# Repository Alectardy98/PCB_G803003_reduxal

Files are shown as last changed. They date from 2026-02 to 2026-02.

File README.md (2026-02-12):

# GH80-3003 Reduxal

Open-sourced Cherry MX PCB using the Pi Pico (RP2040) for the Cherry G80 3001 line of keyboards. Stock keyboards shipped originally with Cherry MY switches.

G803003_REDUXAL_TOP
G803003_REDUXAL_TOP

Original Placement measurements taken from other open-sourced PCB designs.
https://github.com/evyd13/gh80-series
https://github.com/Gacathon/Chili

## Production
Production files in the JLCPCB Folder

## Firmware
Qmk/Vial Firmware in the firmware folder

Use at your own risk.

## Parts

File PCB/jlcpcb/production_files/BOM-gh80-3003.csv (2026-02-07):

Comment | Designator | Footprint | LCSC | Quantity
1k | R4,R7 | R_0402_1005Metric | C11702 | 2
100nF | C12,C13,C14,C15,C16,C17,C18,C5,C8,C9 | C_0402_1005Metric | C1525 | 10
10uF | C10 | C_0402_1005Metric | C15525 | 1
22pF | C2,C3 | C_0402_1005Metric | C1555 | 2
Conn_01x04_MountingPin | J3 | JST_SH_SM04B-SRSS-TB_1x04-1MP_P1.00mm_Horizontal | C160404 | 1
USB_C | J4 | USB_C_Receptacle_HRO_TYPE-C-31-M-12 | C165948 | 1
1k | R106,R107,R108,R5,R6 | R_0805_2012Metric | C17513 | 5
22 | R100 | R_0805_2012Metric | C17561 | 1
RP2040 | U2 | RP2040-QFN-56 | C2040 | 1
D_Small | D1,D10,D100,D101,D102,D103,D104,D105,D106,D107,D11,D110,D111,D112,D113,D114,D115,D116,D117,D118,D119,D121,D122,D124,D126,D127,D128,D129,D13,D130,D131,D14,D15,D16,D17,D18,D19,D2,D20,D21,D22,D24,D25,D26,D27,D29,D3,D30,D31,D32,D35,D37,D38,D39,D4,D40,D41,D42,D43,D44,D45,D46,D47,D48,D49,D5,D50,D51,D52,D53,D54,D55,D57,D58,D59,D6,D60,D61,D62,D63,D64,D65,D66,D67,D68,D69,D7,D70,D71,D72,D73,D74,D75,D76,D77,D78,D79,D8,D80,D81,D82,D83,D84,D85,D86,D87,D88,D89,D9,D90,D91,D92,D93,D94,D95,D96,D97,D98,D99 | D_SOD-123 | C2099 | 119
27R | R2,R3 | R_0603_1608Metric | C25190 | 2
5.1k | R22,R8 | R_0402_1005Metric | C25905 | 2
0.1uF | C1 | C_0805_2012Metric | C49678 | 1
1uF | C11,C4,C6,C7 | C_0402_1005Metric | C52923 | 4
XC6206 | U5 | SOT-23 | C5446 | 1
500mA | F1,F2 | Fuse_1206_3216Metric | C70076 | 2
SRV05-4 | U3 | SOT-23-6-routable | C85364 | 1
12MHz | Y1 | Crystal_SMD_3225-4Pin_3.2x2.5mm | C9002 | 1
W25Q128JVS | U4 | SOIC-8_5.23x5.23mm_P1.27mm | C97521 | 1

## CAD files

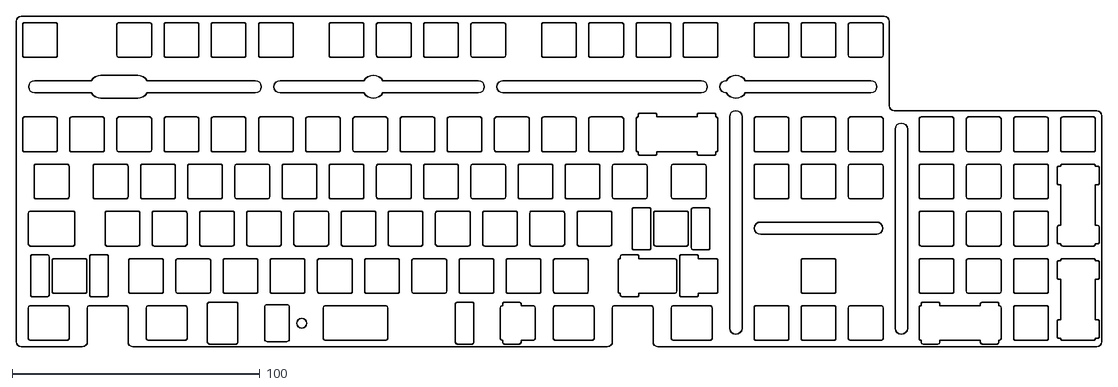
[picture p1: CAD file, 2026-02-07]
plate/gh80-3003-ansi.dxf
438.2 x 133.4

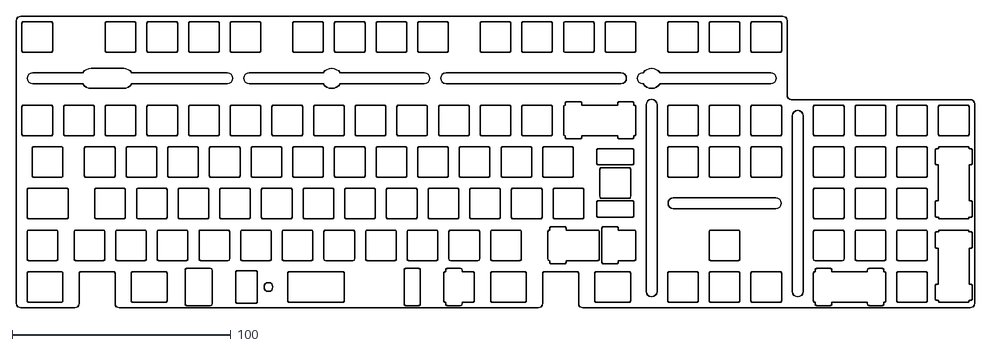
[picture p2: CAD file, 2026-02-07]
plate/gh80-3003-iso.dxf
438.2 x 133.4

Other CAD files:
plate/plate.FCStd

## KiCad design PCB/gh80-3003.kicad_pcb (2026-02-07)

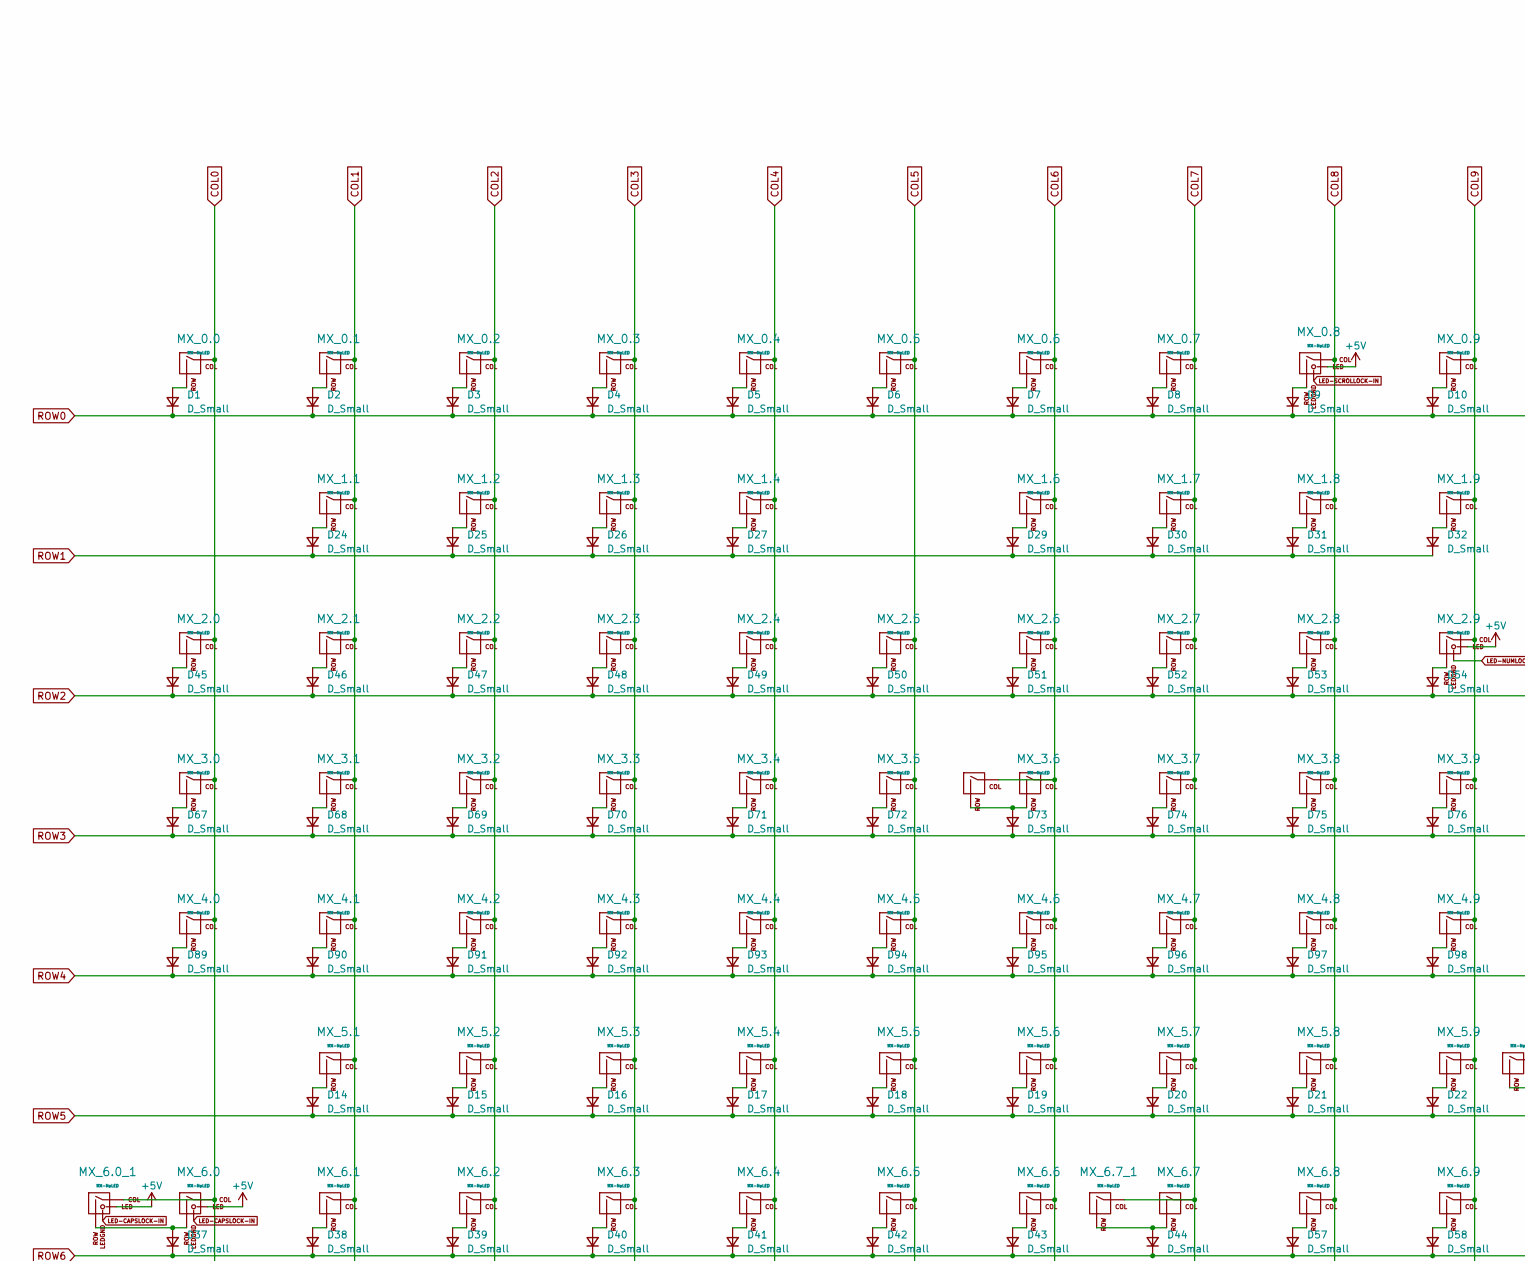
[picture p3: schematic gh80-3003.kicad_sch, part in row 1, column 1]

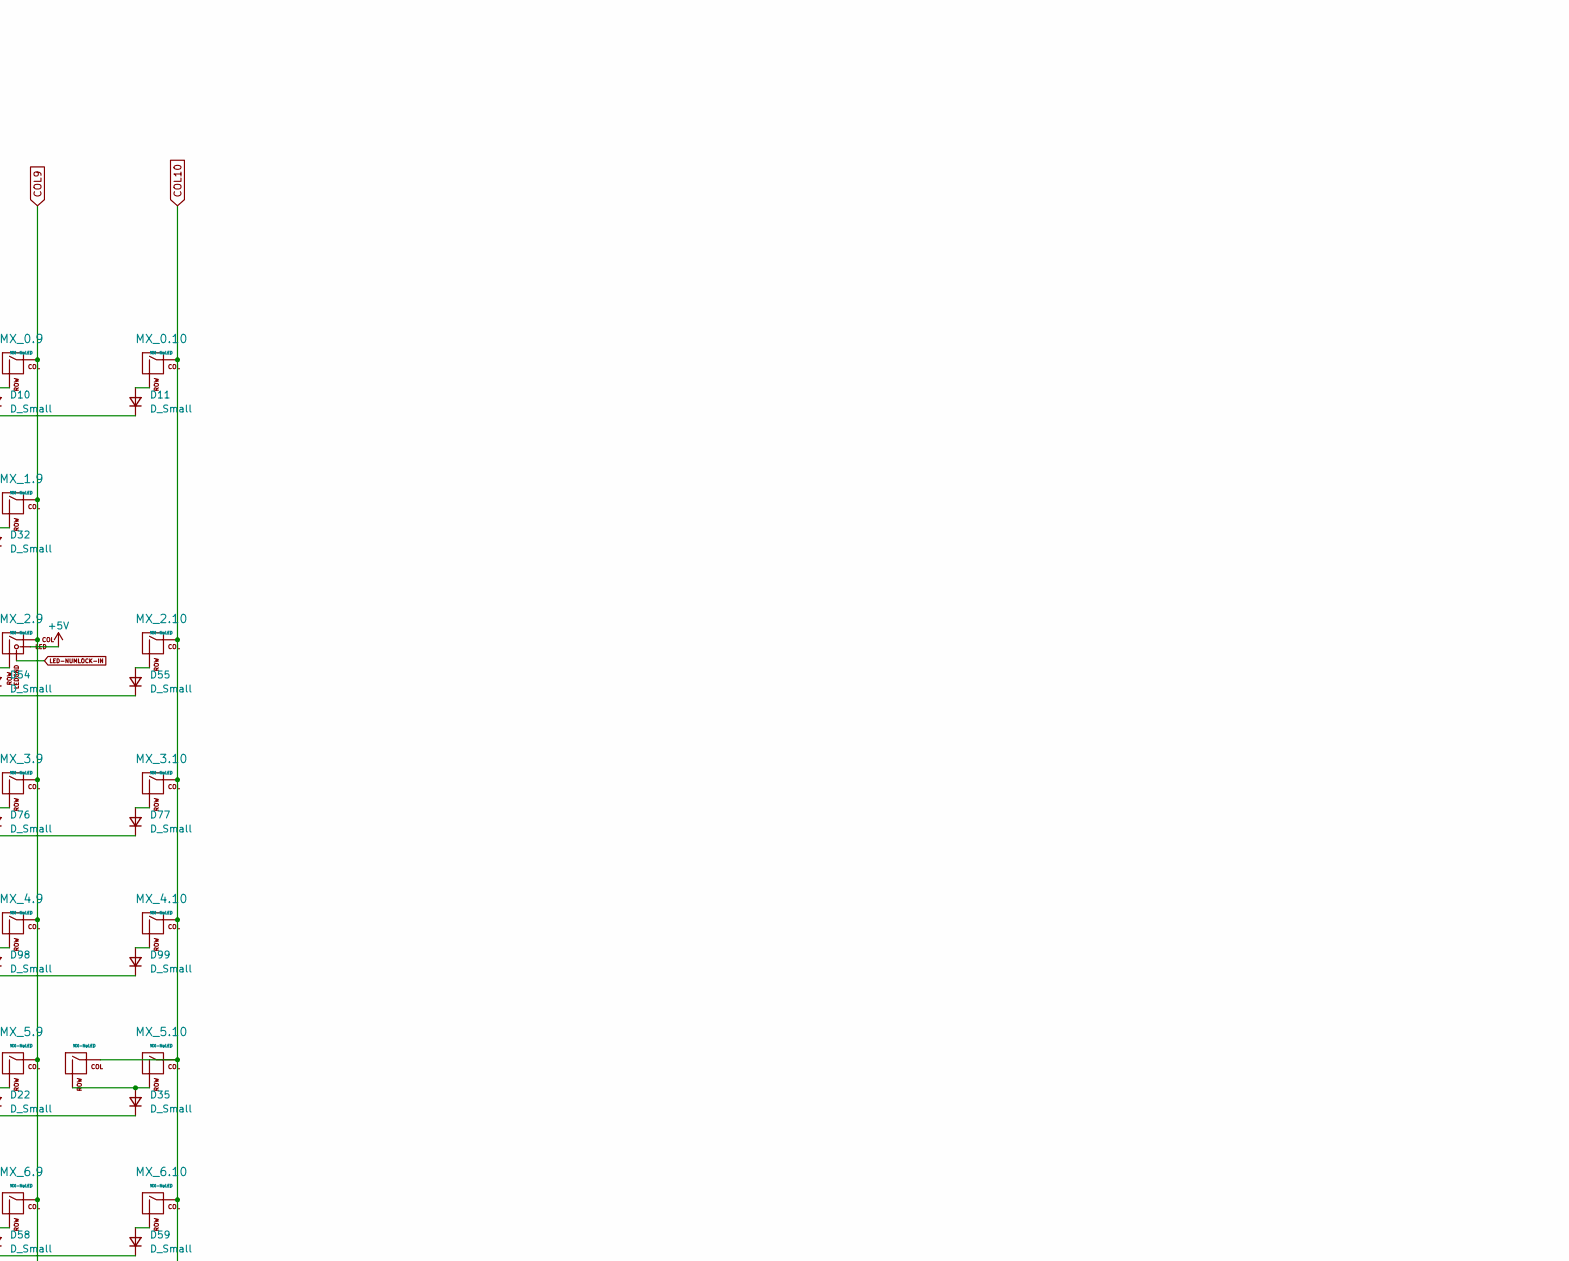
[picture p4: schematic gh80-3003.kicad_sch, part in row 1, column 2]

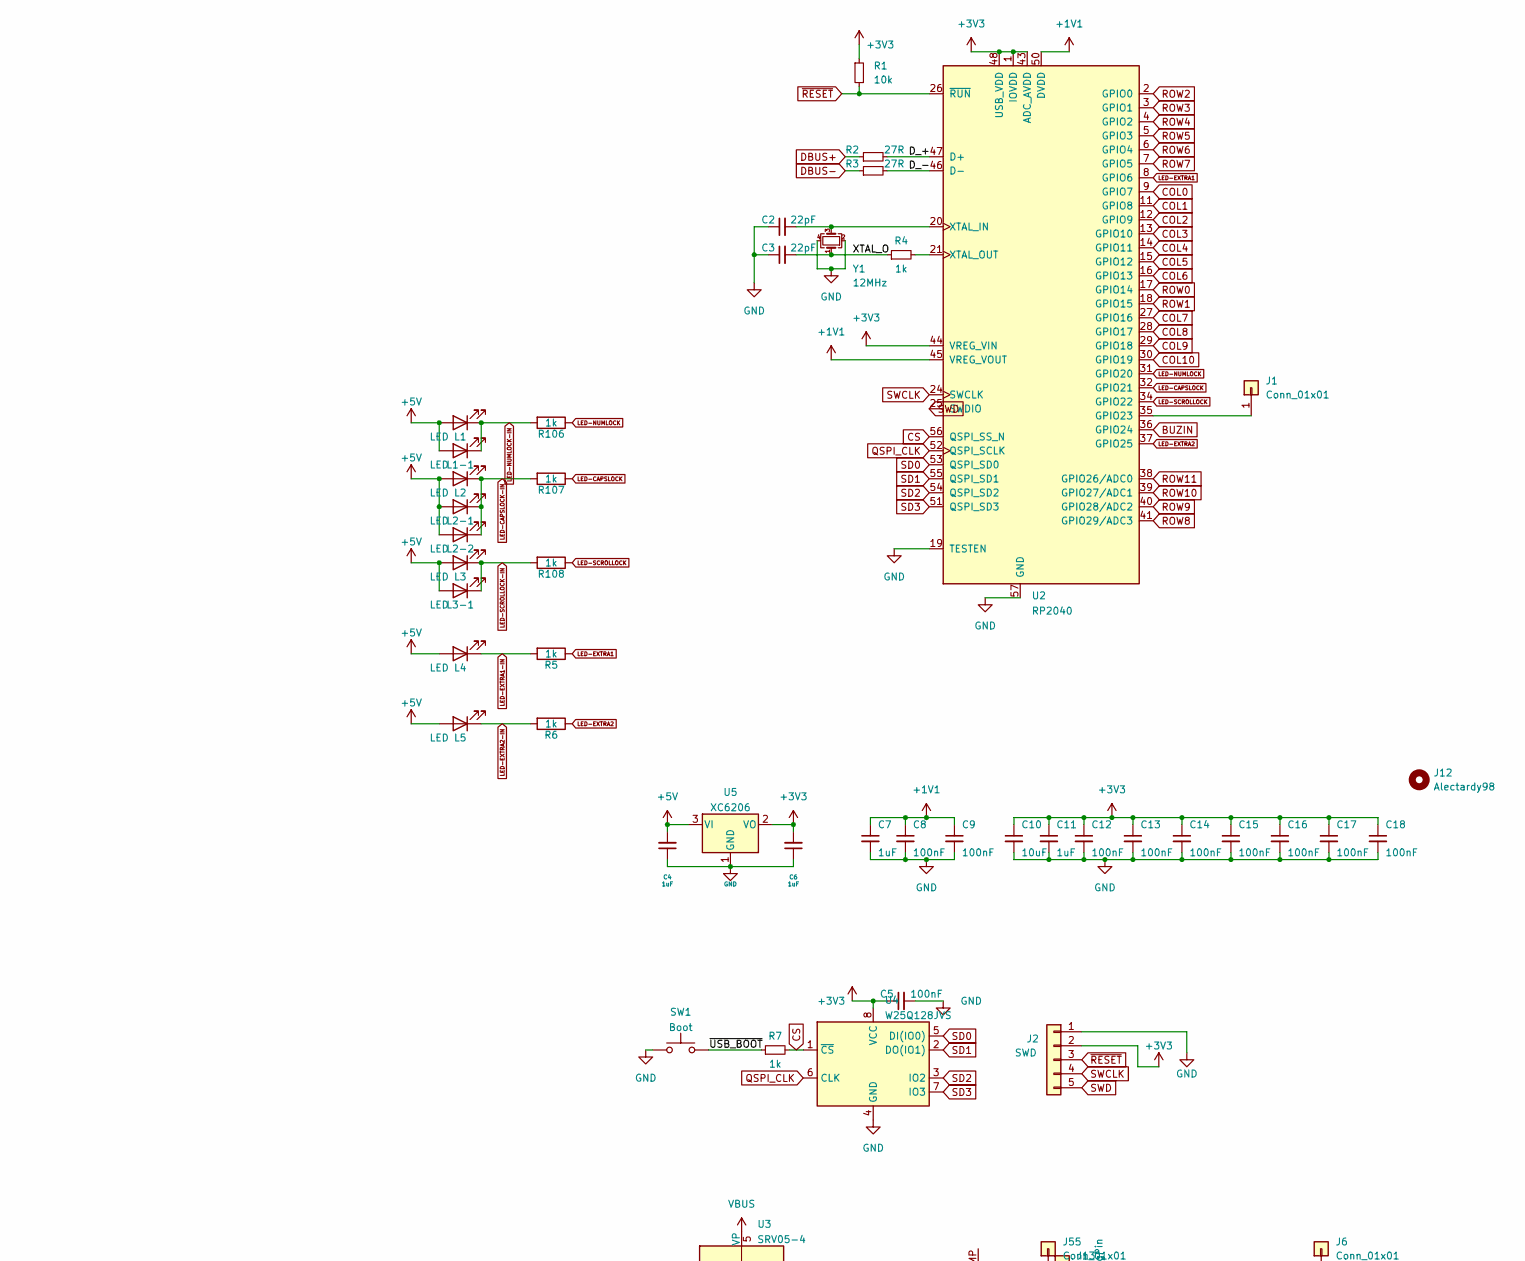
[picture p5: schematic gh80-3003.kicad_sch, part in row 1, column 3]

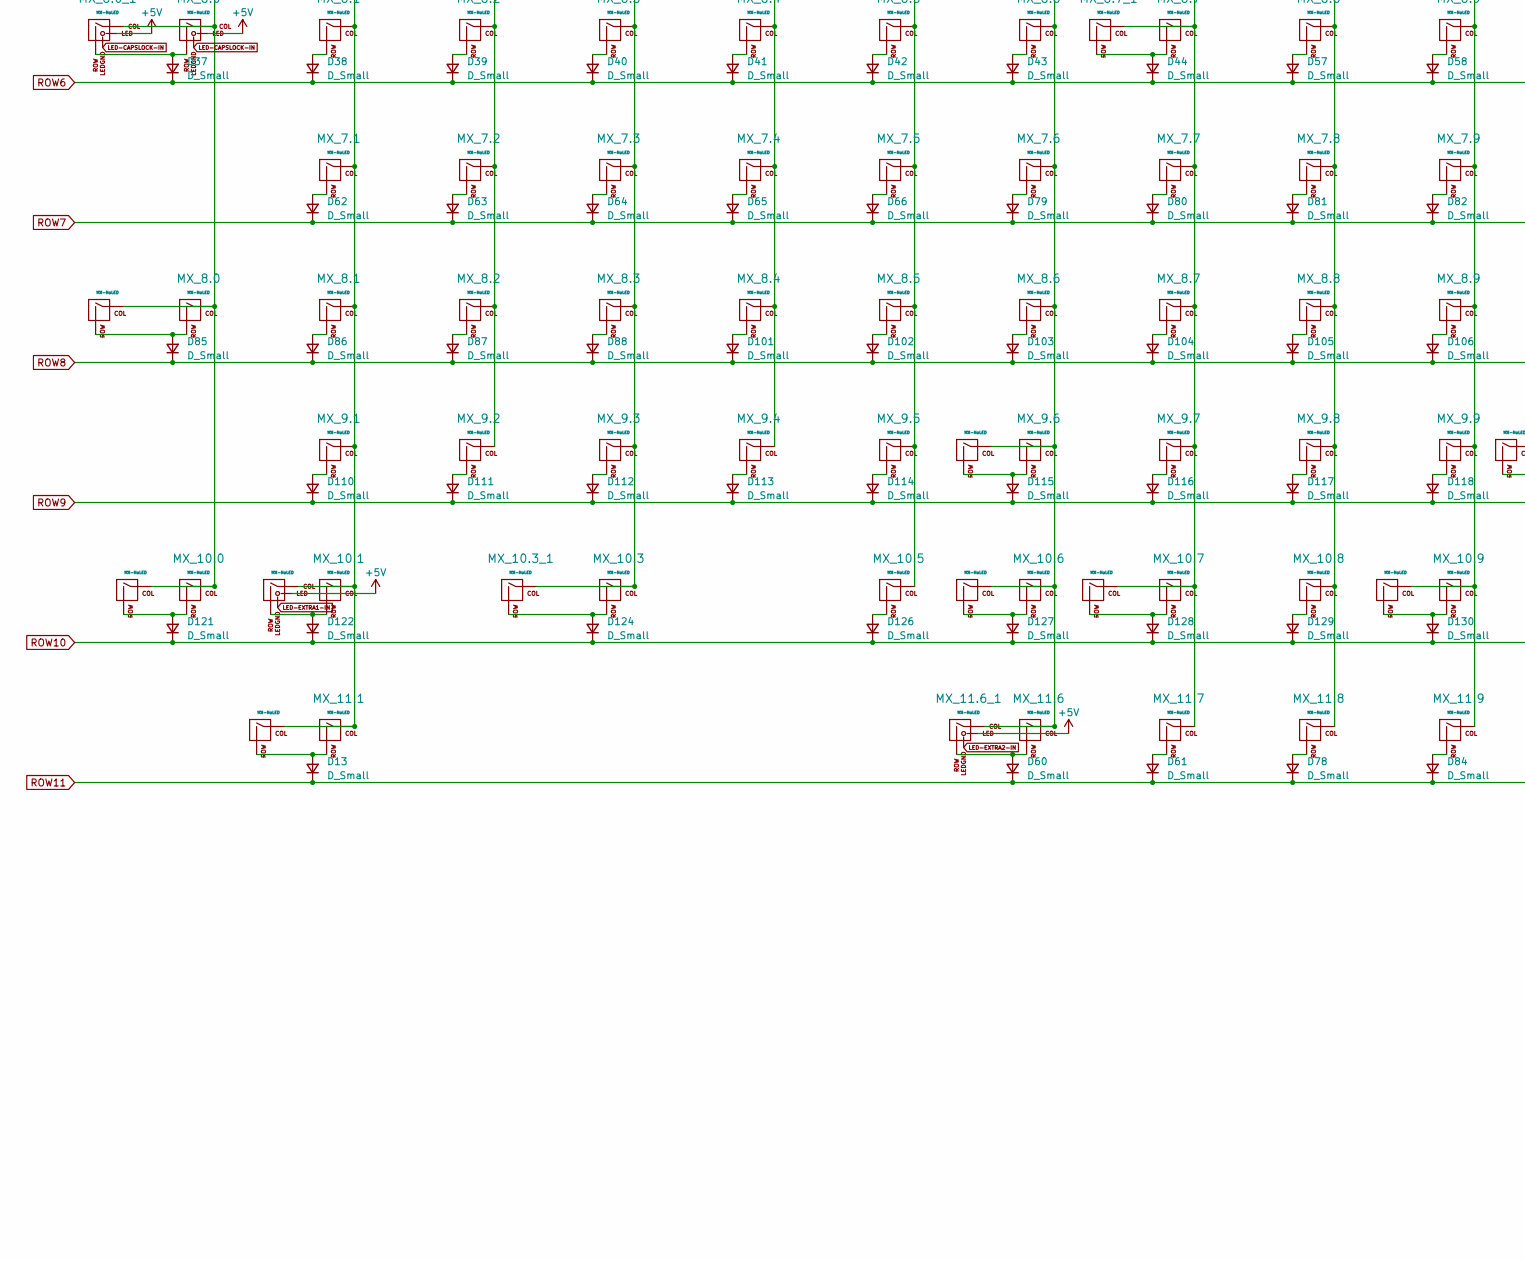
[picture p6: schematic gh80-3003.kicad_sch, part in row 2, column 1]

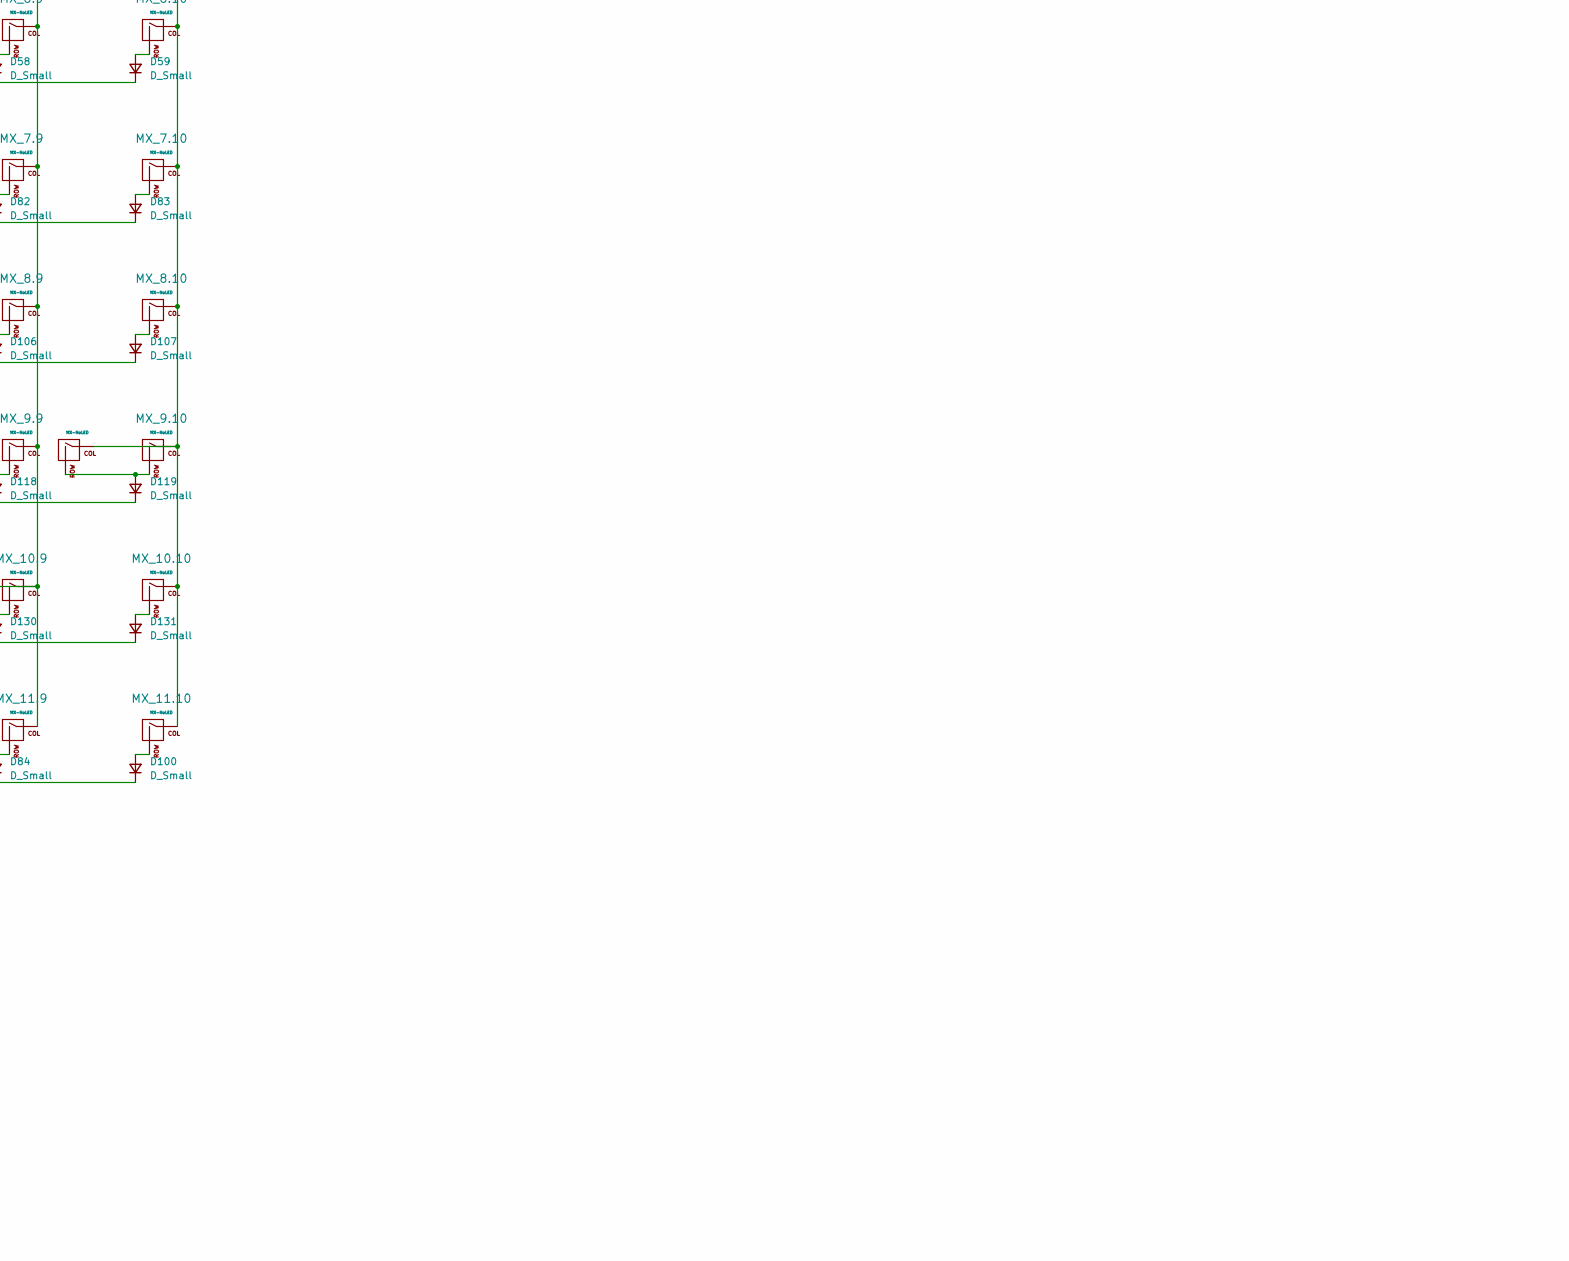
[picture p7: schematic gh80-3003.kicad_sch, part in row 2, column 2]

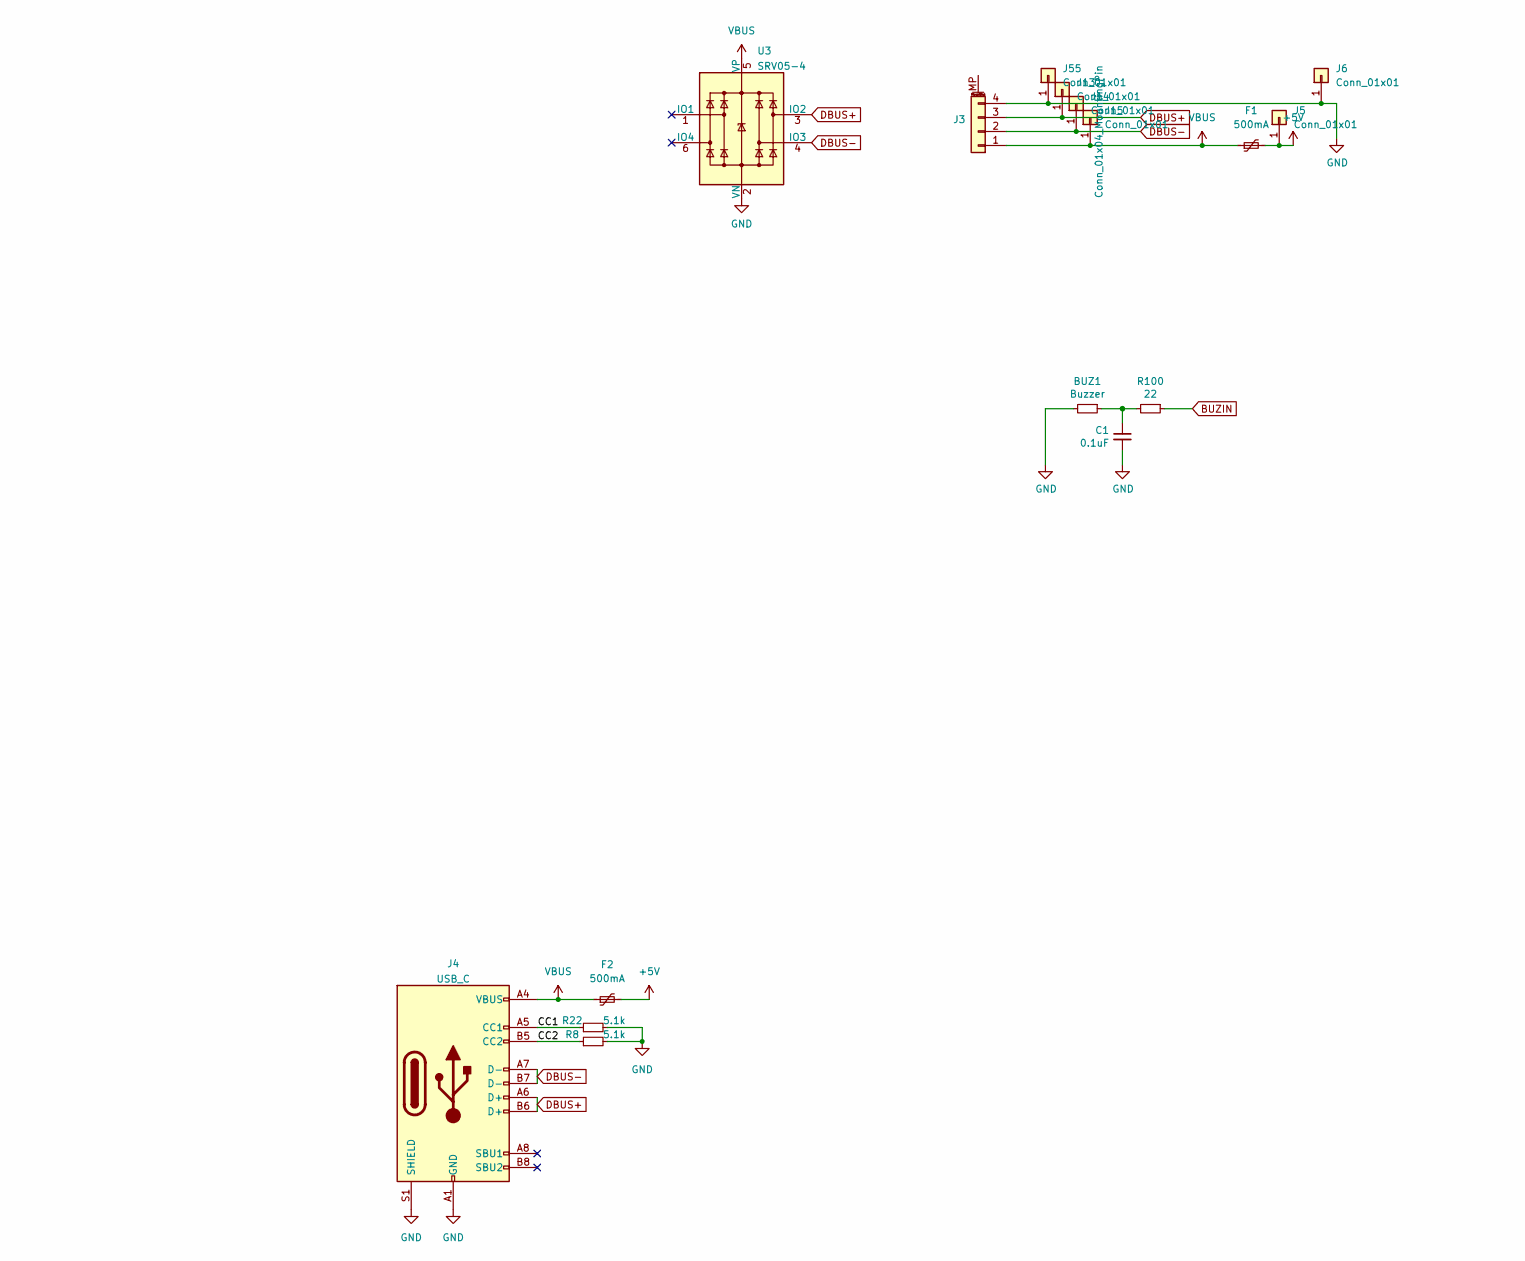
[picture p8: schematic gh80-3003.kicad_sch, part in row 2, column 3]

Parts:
BUZ1: Buzzer; Buzzer_Mallory_AST1109MLTRQ
C1: 0.1uF; C_0805_2012Metric
C2, C3: 22pF; C_0402_1005Metric; LCSC C1555
C4, C6, C7, C11: 1uF; C_0402_1005Metric; LCSC C52923
C5, C8, C9, C12, C13, C14, C15, C16, C17, C18: 100nF; C_0402_1005Metric; LCSC C1525
C10: 10uF; C_0402_1005Metric; LCSC C15525
D1, D2, D3, D4, D5, D6, D7, D8, D9, D10, D11, D13, D14, D15, D16, D17, D18, D19, D20, D21, D22, D24, D25, D26, D27, D29, D30, D31, D32, D35, D37, D38, D39, D40, D41, D42, D43, D44, D45, D46, D47, D48, D49, D50, D51, D52, D53, D54, D55, D57, D58, D59, D60, D61, D62, D63, D64, D65, D66, D67, D68, D69, D70, D71, D72, D73, D74, D75, D76, D77, D78, D79, D80, D81, D82, D83, D84, D85, D86, D87, D88, D89, D90, D91, D92, D93, D94, D95, D96, D97, D98, D99, D100, D101, D102, D103, D104, D105, D106, D107, D110, D111, D112, D113, D114, D115, D116, D117, D118, D119, D121, D122, D124, D126, D127, D128, D129, D130, D131: D_Small; D_SOD-123
F1, F2: 500mA; Fuse_1206_3216Metric; LCSC C70076
J1, J5, J6, J13, J14, J15, J55: Conn_01x01; TestPoint_Plated_Hole_D2.0mm
J2: SWD; PinSocket_1x05_P2.54mm_Vertical
J3: Conn_01x04_MountingPin; JST_SH_SM04B-SRSS-TB_1x04-1MP_P1.00mm_Horizontal
J4: USB_C; USB_C_Receptacle_HRO_TYPE-C-31-M-12; LCSC C165948
J12: Alectardy98; Alectardy98101
L1, L2, L3: LED; LED_D3.0mm
L1-1, L2-1, L2-2, L3-1, L4, L5: LED; CHERRY_MX_LED
MX_0.0, MX_0.1, MX_0.2, MX_0.3, MX_0.4, MX_0.5, MX_0.6, MX_0.7, MX_0.9, MX_0.10, MX_1.1, MX_1.2, MX_1.3, MX_1.4, MX_1.6, MX_1.7, MX_1.8, MX_1.9, MX_2.0, MX_2.1, MX_2.2, MX_2.3, MX_2.4, MX_2.5, MX_2.6, MX_2.7, MX_2.8, MX_2.10, MX_3.0, MX_3.1, MX_3.2, MX_3.3, MX_3.4, MX_3.5, MX_3.6, MX_3.7, MX_3.8, MX_3.9, MX_3.10, MX_4.1, MX_4.2, MX_4.3, MX_4.4, MX_4.5, MX_4.6, MX_4.8, MX_4.9, MX_4.10, MX_5.1, MX_5.2, MX_5.3, MX_5.4, MX_5.5, MX_5.6, MX_5.7, MX_5.8, MX_5.9, MX_5.10, MX_6.1, MX_6.2, MX_6.3, MX_6.4, MX_6.5, MX_6.6, MX_6.8, MX_6.9, MX_6.10, MX_7.1, MX_7.2, MX_7.3, MX_7.4, MX_7.5, MX_7.6, MX_7.7, MX_7.8, MX_7.9, MX_7.10, MX_8.1, MX_8.2, MX_8.3, MX_8.4, MX_8.5, MX_8.6, MX_8.7, MX_8.8, MX_8.9, MX_8.10, MX_9.1, MX_9.2, MX_9.3, MX_9.4, MX_9.5, MX_9.7, MX_9.8, MX_9.9, MX_9.10, MX_10.8, MX_10.9, MX_10.10, MX_11.7, MX_11.8, MX_11.9, MX_11.10: MX-NoLED; MXOnly-1U-NoLED
MX_0.8, MX_2.9, MX_10.1_1, MX_11.6_1: MX-NoLED; MXOnly-1U
MX_3.6_1, MX_10.9_1: MX-NoLED; MXOnly-2U-NoLED
MX_4.0, MX_4.7, MX_10.0_1, MX_10.6_1, MX_10.7_1, MX_11.1_1: MX-NoLED; MXOnly-1.5U-NoLED
MX_5.10_1, MX_9.10_1: MX-NoLED; MXOnly-2U-VerticalStabilizers-NoLED
MX_6.0: MX-NoLED; MXOnly-1.75U
MX_6.0_1: MX-NoLED; MXOnly-1.25U
MX_6.7, MX_8.0_1: MX-NoLED; MXOnly-2.25U-NoLED
MX_6.7_1: MX-NoLED; MXOnly-ISO-ReversedStabilizers-NoLED
MX_8.0, MX_10.0, MX_10.1, MX_10.5, MX_10.6, MX_10.7, MX_11.1, MX_11.6: MX-NoLED; MXOnly-1.25U-NoLED
MX_9.6: MX-NoLED; MXOnly-1.75U-NoLED
MX_9.6_1: MX-NoLED; MXOnly-2.75U-NoLED
MX_10.3: MX-NoLED; MXOnly-6.25U-NoLED
MX_10.3_1: MX-NoLED; MXOnly-7U-NoLED
R1: 10k; R_0402_1005Metric; LCSC C25744
R2, R3: 27R; R_0603_1608Metric; LCSC C25190
R4, R7: 1k; R_0402_1005Metric; LCSC C11702
R5, R6, R106, R107, R108: 1k; R_0805_2012Metric
R8, R22: 5.1k; R_0402_1005Metric; LCSC C25905
R100: 22; R_0805_2012Metric
SW1: Boot; PinSocket_1x02_P2.54mm_Vertical
U2: RP2040; RP2040-QFN-56; LCSC C2040
U3: SRV05-4; SOT-23-6-routable; LCSC C85364
U4: W25Q128JVS; SOIC-8_5.23x5.23mm_P1.27mm; LCSC C97521
U5: XC6206; SOT-23; LCSC C5446
Y1: 12MHz; Crystal_SMD_3225-4Pin_3.2x2.5mm; LCSC C9002

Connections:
+1V1: C7.1, C8.1, C9.1, U2.23 (DVDD), U2.45 (VREG_VOUT), U2.50 (DVDD)
+3V3: C5.1, C6.2, C10.1, C11.1, C12.1, C13.1, C14.1, C15.1, C16.1, C17.1, C18.1, J2.2, R1.1, U2.1 (IOVDD), U2.10 (IOVDD), U2.22 (IOVDD), U2.33 (IOVDD), U2.42 (IOVDD), U2.43 (ADC_AVDD), U2.44 (VREG_VIN), U2.48 (USB_VDD), U2.49 (IOVDD), U4.8 (VCC), U5.2 (VO)
+5V: C4.2, F1.2, F2.2, J5.1, L1.2 (A), L1-1.2 (A), L2.2 (A), L2-1.2 (A), L2-2.2 (A), L3.2 (A), L3-1.2 (A), L4.2 (A), L5.2 (A), MX_0.8.3 (LED), MX_2.9.3 (LED), MX_6.0.3 (LED), MX_6.0_1.3 (LED), MX_10.1_1.3 (LED), MX_11.6_1.3 (LED), U5.3 (VI)
/CC1: J4.A5 (CC1), R22.1
/CC2: J4.B5 (CC2), R8.1
/D_+: R2.2, U2.47 (D+)
/D_-: R3.2, U2.46 (D-)
/XTAL_O: C3.2, R4.1, Y1.1
/~USB_BOOT: R7.1, SW1.2
BUZIN: R100.1, U2.36 (GPIO24)
COL0: MX_0.0.1 (COL), MX_2.0.1 (COL), MX_3.0.1 (COL), MX_4.0.1 (COL), MX_6.0.1 (COL), MX_6.0_1.1 (COL), MX_8.0.1 (COL), MX_8.0_1.1 (COL), MX_10.0.1 (COL), MX_10.0_1.1 (COL), U2.9 (GPIO7)
COL1: MX_0.1.1 (COL), MX_1.1.1 (COL), MX_2.1.1 (COL), MX_3.1.1 (COL), MX_4.1.1 (COL), MX_5.1.1 (COL), MX_6.1.1 (COL), MX_7.1.1 (COL), MX_8.1.1 (COL), MX_9.1.1 (COL), MX_10.1.1 (COL), MX_10.1_1.1 (COL), MX_11.1.1 (COL), MX_11.1_1.1 (COL), U2.11 (GPIO8)
COL2: MX_0.2.1 (COL), MX_1.2.1 (COL), MX_2.2.1 (COL), MX_3.2.1 (COL), MX_4.2.1 (COL), MX_5.2.1 (COL), MX_6.2.1 (COL), MX_7.2.1 (COL), MX_8.2.1 (COL), MX_9.2.1 (COL), U2.12 (GPIO9)
COL3: MX_0.3.1 (COL), MX_1.3.1 (COL), MX_2.3.1 (COL), MX_3.3.1 (COL), MX_4.3.1 (COL), MX_5.3.1 (COL), MX_6.3.1 (COL), MX_7.3.1 (COL), MX_8.3.1 (COL), MX_9.3.1 (COL), MX_10.3.1 (COL), MX_10.3_1.1 (COL), U2.13 (GPIO10)
COL4: MX_0.4.1 (COL), MX_1.4.1 (COL), MX_2.4.1 (COL), MX_3.4.1 (COL), MX_4.4.1 (COL), MX_5.4.1 (COL), MX_6.4.1 (COL), MX_7.4.1 (COL), MX_8.4.1 (COL), MX_9.4.1 (COL), U2.14 (GPIO11)
COL5: MX_0.5.1 (COL), MX_2.5.1 (COL), MX_3.5.1 (COL), MX_4.5.1 (COL), MX_5.5.1 (COL), MX_6.5.1 (COL), MX_7.5.1 (COL), MX_8.5.1 (COL), MX_9.5.1 (COL), MX_10.5.1 (COL), U2.15 (GPIO12)
COL6: MX_0.6.1 (COL), MX_1.6.1 (COL), MX_2.6.1 (COL), MX_3.6.1 (COL), MX_3.6_1.1 (COL), MX_4.6.1 (COL), MX_5.6.1 (COL), MX_6.6.1 (COL), MX_7.6.1 (COL), MX_8.6.1 (COL), MX_9.6.1 (COL), MX_9.6_1.1 (COL), MX_10.6.1 (COL), MX_10.6_1.1 (COL), MX_11.6.1 (COL), MX_11.6_1.1 (COL), U2.16 (GPIO13)
COL7: MX_0.7.1 (COL), MX_1.7.1 (COL), MX_2.7.1 (COL), MX_3.7.1 (COL), MX_4.7.1 (COL), MX_5.7.1 (COL), MX_6.7.1 (COL), MX_6.7_1.1 (COL), MX_7.7.1 (COL), MX_8.7.1 (COL), MX_9.7.1 (COL), MX_10.7.1 (COL), MX_10.7_1.1 (COL), MX_11.7.1 (COL), U2.27 (GPIO16)
COL8: MX_0.8.1 (COL), MX_1.8.1 (COL), MX_2.8.1 (COL), MX_3.8.1 (COL), MX_4.8.1 (COL), MX_5.8.1 (COL), MX_6.8.1 (COL), MX_7.8.1 (COL), MX_8.8.1 (COL), MX_9.8.1 (COL), MX_10.8.1 (COL), MX_11.8.1 (COL), U2.28 (GPIO17)
COL9: MX_0.9.1 (COL), MX_1.9.1 (COL), MX_2.9.1 (COL), MX_3.9.1 (COL), MX_4.9.1 (COL), MX_5.9.1 (COL), MX_6.9.1 (COL), MX_7.9.1 (COL), MX_8.9.1 (COL), MX_9.9.1 (COL), MX_10.9.1 (COL), MX_10.9_1.1 (COL), MX_11.9.1 (COL), U2.29 (GPIO18)
COL10: MX_0.10.1 (COL), MX_2.10.1 (COL), MX_3.10.1 (COL), MX_4.10.1 (COL), MX_5.10.1 (COL), MX_5.10_1.1 (COL), MX_6.10.1 (COL), MX_7.10.1 (COL), MX_8.10.1 (COL), MX_9.10.1 (COL), MX_9.10_1.1 (COL), MX_10.10.1 (COL), MX_11.10.1 (COL), U2.30 (GPIO19)
CS: R7.2, U2.56 (QSPI_SS_N), U4.1 (~CS)
DBUS+: J3.3, J4.A6 (D+), J4.B6 (D+), J13.1, R2.1, U3.3 (IO2)
DBUS-: J3.2, J4.A7 (D-), J4.B7 (D-), J14.1, R3.1, U3.4 (IO3)
GND: BUZ1.2, C1.2, C2.1, C3.1, C4.1, C5.2, C6.1, C7.2, C8.2, C9.2, C10.2, C11.2, C12.2, C13.2, C14.2, C15.2, C16.2, C17.2, C18.2, J2.1, J3.4, J4.A1 (GND), J4.A12 (GND), J4.B1 (GND), J4.B12 (GND), J4.S1 (SHIELD), J6.1, J55.1, R8.2, R22.2, SW1.1, U2.19 (TESTEN), U2.57 (GND), U3.2 (VN), U4.4 (GND), U5.1 (GND), Y1.2, Y1.4
LED-CAPSLOCK: R107.1, U2.32 (GPIO21)
LED-CAPSLOCK-IN: L2.1 (K), L2-1.1 (K), L2-2.1 (K), MX_6.0.4 (LEDGND), MX_6.0_1.4 (LEDGND), R107.2
LED-EXTRA1: R5.1, U2.8 (GPIO6)
LED-EXTRA1-IN: L4.1 (K), MX_10.1_1.4 (LEDGND), R5.2
LED-EXTRA2: R6.1, U2.37 (GPIO25)
LED-EXTRA2-IN: L5.1 (K), MX_11.6_1.4 (LEDGND), R6.2
LED-NUMLOCK: R106.1, U2.31 (GPIO20)
LED-NUMLOCK-IN: L1.1 (K), L1-1.1 (K), MX_2.9.4 (LEDGND), R106.2
LED-SCROLLOCK: R108.1, U2.34 (GPIO22)
LED-SCROLLOCK-IN: L3.1 (K), L3-1.1 (K), MX_0.8.4 (LEDGND), R108.2
unnamed: BUZ1.1, C1.1, R100.2
unnamed: D1.2 (A), MX_0.0.2 (ROW)
unnamed: D2.2 (A), MX_0.1.2 (ROW)
unnamed: D3.2 (A), MX_0.2.2 (ROW)
unnamed: D4.2 (A), MX_0.3.2 (ROW)
unnamed: D5.2 (A), MX_0.4.2 (ROW)
unnamed: D6.2 (A), MX_0.5.2 (ROW)
unnamed: D7.2 (A), MX_0.6.2 (ROW)
unnamed: D8.2 (A), MX_0.7.2 (ROW)
unnamed: D9.2 (A), MX_0.8.2 (ROW)
unnamed: D10.2 (A), MX_0.9.2 (ROW)
unnamed: D11.2 (A), MX_0.10.2 (ROW)
unnamed: D13.2 (A), MX_11.1.2 (ROW), MX_11.1_1.2 (ROW)
unnamed: D14.2 (A), MX_5.1.2 (ROW)
unnamed: D15.2 (A), MX_5.2.2 (ROW)
unnamed: D16.2 (A), MX_5.3.2 (ROW)
unnamed: D17.2 (A), MX_5.4.2 (ROW)
unnamed: D18.2 (A), MX_5.5.2 (ROW)
unnamed: D19.2 (A), MX_5.6.2 (ROW)
unnamed: D20.2 (A), MX_5.7.2 (ROW)
unnamed: D21.2 (A), MX_5.8.2 (ROW)
unnamed: D22.2 (A), MX_5.9.2 (ROW)
unnamed: D24.2 (A), MX_1.1.2 (ROW)
unnamed: D25.2 (A), MX_1.2.2 (ROW)
unnamed: D26.2 (A), MX_1.3.2 (ROW)
unnamed: D27.2 (A), MX_1.4.2 (ROW)
unnamed: D29.2 (A), MX_1.6.2 (ROW)
unnamed: D30.2 (A), MX_1.7.2 (ROW)
unnamed: D31.2 (A), MX_1.8.2 (ROW)
unnamed: D32.2 (A), MX_1.9.2 (ROW)
unnamed: D35.2 (A), MX_5.10.2 (ROW), MX_5.10_1.2 (ROW)
unnamed: D37.2 (A), MX_6.0.2 (ROW), MX_6.0_1.2 (ROW)
unnamed: D38.2 (A), MX_6.1.2 (ROW)
unnamed: D39.2 (A), MX_6.2.2 (ROW)
unnamed: D40.2 (A), MX_6.3.2 (ROW)
unnamed: D41.2 (A), MX_6.4.2 (ROW)
unnamed: D42.2 (A), MX_6.5.2 (ROW)
unnamed: D43.2 (A), MX_6.6.2 (ROW)
unnamed: D44.2 (A), MX_6.7.2 (ROW), MX_6.7_1.2 (ROW)
unnamed: D45.2 (A), MX_2.0.2 (ROW)
unnamed: D46.2 (A), MX_2.1.2 (ROW)
unnamed: D47.2 (A), MX_2.2.2 (ROW)
unnamed: D48.2 (A), MX_2.3.2 (ROW)
unnamed: D49.2 (A), MX_2.4.2 (ROW)
unnamed: D50.2 (A), MX_2.5.2 (ROW)
unnamed: D51.2 (A), MX_2.6.2 (ROW)
unnamed: D52.2 (A), MX_2.7.2 (ROW)
unnamed: D53.2 (A), MX_2.8.2 (ROW)
unnamed: D54.2 (A), MX_2.9.2 (ROW)
unnamed: D55.2 (A), MX_2.10.2 (ROW)
unnamed: D57.2 (A), MX_6.8.2 (ROW)
unnamed: D58.2 (A), MX_6.9.2 (ROW)
unnamed: D59.2 (A), MX_6.10.2 (ROW)
unnamed: D60.2 (A), MX_11.6.2 (ROW), MX_11.6_1.2 (ROW)
unnamed: D61.2 (A), MX_11.7.2 (ROW)
unnamed: D62.2 (A), MX_7.1.2 (ROW)
unnamed: D63.2 (A), MX_7.2.2 (ROW)
unnamed: D64.2 (A), MX_7.3.2 (ROW)
unnamed: D65.2 (A), MX_7.4.2 (ROW)
unnamed: D66.2 (A), MX_7.5.2 (ROW)
unnamed: D67.2 (A), MX_3.0.2 (ROW)
unnamed: D68.2 (A), MX_3.1.2 (ROW)
unnamed: D69.2 (A), MX_3.2.2 (ROW)
unnamed: D70.2 (A), MX_3.3.2 (ROW)
unnamed: D71.2 (A), MX_3.4.2 (ROW)
unnamed: D72.2 (A), MX_3.5.2 (ROW)
unnamed: D73.2 (A), MX_3.6.2 (ROW), MX_3.6_1.2 (ROW)
unnamed: D74.2 (A), MX_3.7.2 (ROW)
unnamed: D75.2 (A), MX_3.8.2 (ROW)
unnamed: D76.2 (A), MX_3.9.2 (ROW)
unnamed: D77.2 (A), MX_3.10.2 (ROW)
unnamed: D78.2 (A), MX_11.8.2 (ROW)
unnamed: D79.2 (A), MX_7.6.2 (ROW)
unnamed: D80.2 (A), MX_7.7.2 (ROW)
unnamed: D81.2 (A), MX_7.8.2 (ROW)
unnamed: D82.2 (A), MX_7.9.2 (ROW)
unnamed: D83.2 (A), MX_7.10.2 (ROW)
unnamed: D84.2 (A), MX_11.9.2 (ROW)
unnamed: D85.2 (A), MX_8.0.2 (ROW), MX_8.0_1.2 (ROW)
unnamed: D86.2 (A), MX_8.1.2 (ROW)
unnamed: D87.2 (A), MX_8.2.2 (ROW)
unnamed: D88.2 (A), MX_8.3.2 (ROW)
unnamed: D89.2 (A), MX_4.0.2 (ROW)
unnamed: D90.2 (A), MX_4.1.2 (ROW)
unnamed: D91.2 (A), MX_4.2.2 (ROW)
unnamed: D92.2 (A), MX_4.3.2 (ROW)
unnamed: D93.2 (A), MX_4.4.2 (ROW)
unnamed: D94.2 (A), MX_4.5.2 (ROW)
unnamed: D95.2 (A), MX_4.6.2 (ROW)
unnamed: D96.2 (A), MX_4.7.2 (ROW)
unnamed: D97.2 (A), MX_4.8.2 (ROW)
unnamed: D98.2 (A), MX_4.9.2 (ROW)
unnamed: D99.2 (A), MX_4.10.2 (ROW)
unnamed: D100.2 (A), MX_11.10.2 (ROW)
unnamed: D101.2 (A), MX_8.4.2 (ROW)
unnamed: D102.2 (A), MX_8.5.2 (ROW)
unnamed: D103.2 (A), MX_8.6.2 (ROW)
unnamed: D104.2 (A), MX_8.7.2 (ROW)
unnamed: D105.2 (A), MX_8.8.2 (ROW)
unnamed: D106.2 (A), MX_8.9.2 (ROW)
unnamed: D107.2 (A), MX_8.10.2 (ROW)
unnamed: D110.2 (A), MX_9.1.2 (ROW)
unnamed: D111.2 (A), MX_9.2.2 (ROW)
unnamed: D112.2 (A), MX_9.3.2 (ROW)
unnamed: D113.2 (A), MX_9.4.2 (ROW)
unnamed: D114.2 (A), MX_9.5.2 (ROW)
unnamed: D115.2 (A), MX_9.6.2 (ROW), MX_9.6_1.2 (ROW)
unnamed: D116.2 (A), MX_9.7.2 (ROW)
unnamed: D117.2 (A), MX_9.8.2 (ROW)
unnamed: D118.2 (A), MX_9.9.2 (ROW)
unnamed: D119.2 (A), MX_9.10.2 (ROW), MX_9.10_1.2 (ROW)
unnamed: D121.2 (A), MX_10.0.2 (ROW), MX_10.0_1.2 (ROW)
unnamed: D122.2 (A), MX_10.1.2 (ROW), MX_10.1_1.2 (ROW)
unnamed: D124.2 (A), MX_10.3.2 (ROW), MX_10.3_1.2 (ROW)
unnamed: D126.2 (A), MX_10.5.2 (ROW)
unnamed: D127.2 (A), MX_10.6.2 (ROW), MX_10.6_1.2 (ROW)
unnamed: D128.2 (A), MX_10.7.2 (ROW), MX_10.7_1.2 (ROW)
unnamed: D129.2 (A), MX_10.8.2 (ROW)
unnamed: D130.2 (A), MX_10.9.2 (ROW), MX_10.9_1.2 (ROW)
unnamed: D131.2 (A), MX_10.10.2 (ROW)
unnamed: J1.1, U2.35 (GPIO23)
unnamed: C2.2, U2.20 (XTAL_IN), Y1.3
unnamed: R4.2, U2.21 (XTAL_OUT)
QSPI_CLK: U2.52 (QSPI_SCLK), U4.6 (CLK)
ROW0: D1.1 (K), D2.1 (K), D3.1 (K), D4.1 (K), D5.1 (K), D6.1 (K), D7.1 (K), D8.1 (K), D9.1 (K), D10.1 (K), D11.1 (K), U2.17 (GPIO14)
ROW1: D24.1 (K), D25.1 (K), D26.1 (K), D27.1 (K), D29.1 (K), D30.1 (K), D31.1 (K), D32.1 (K), U2.18 (GPIO15)
ROW2: D45.1 (K), D46.1 (K), D47.1 (K), D48.1 (K), D49.1 (K), D50.1 (K), D51.1 (K), D52.1 (K), D53.1 (K), D54.1 (K), D55.1 (K), U2.2 (GPIO0)
ROW3: D67.1 (K), D68.1 (K), D69.1 (K), D70.1 (K), D71.1 (K), D72.1 (K), D73.1 (K), D74.1 (K), D75.1 (K), D76.1 (K), D77.1 (K), U2.3 (GPIO1)
ROW4: D89.1 (K), D90.1 (K), D91.1 (K), D92.1 (K), D93.1 (K), D94.1 (K), D95.1 (K), D96.1 (K), D97.1 (K), D98.1 (K), D99.1 (K), U2.4 (GPIO2)
ROW5: D14.1 (K), D15.1 (K), D16.1 (K), D17.1 (K), D18.1 (K), D19.1 (K), D20.1 (K), D21.1 (K), D22.1 (K), D35.1 (K), U2.5 (GPIO3)
ROW6: D37.1 (K), D38.1 (K), D39.1 (K), D40.1 (K), D41.1 (K), D42.1 (K), D43.1 (K), D44.1 (K), D57.1 (K), D58.1 (K), D59.1 (K), U2.6 (GPIO4)
ROW7: D62.1 (K), D63.1 (K), D64.1 (K), D65.1 (K), D66.1 (K), D79.1 (K), D80.1 (K), D81.1 (K), D82.1 (K), D83.1 (K), U2.7 (GPIO5)
ROW8: D85.1 (K), D86.1 (K), D87.1 (K), D88.1 (K), D101.1 (K), D102.1 (K), D103.1 (K), D104.1 (K), D105.1 (K), D106.1 (K), D107.1 (K), U2.41 (GPIO29/ADC3)
ROW9: D110.1 (K), D111.1 (K), D112.1 (K), D113.1 (K), D114.1 (K), D115.1 (K), D116.1 (K), D117.1 (K), D118.1 (K), D119.1 (K), U2.40 (GPIO28/ADC2)
ROW10: D121.1 (K), D122.1 (K), D124.1 (K), D126.1 (K), D127.1 (K), D128.1 (K), D129.1 (K), D130.1 (K), D131.1 (K), U2.39 (GPIO27/ADC1)
ROW11: D13.1 (K), D60.1 (K), D61.1 (K), D78.1 (K), D84.1 (K), D100.1 (K), U2.38 (GPIO26/ADC0)
SD0: U2.53 (QSPI_SD0), U4.5 (DI(IO0))
SD1: U2.55 (QSPI_SD1), U4.2 (DO(IO1))
SD2: U2.54 (QSPI_SD2), U4.3 (IO2)
SD3: U2.51 (QSPI_SD3), U4.7 (IO3)
SWCLK: J2.4, U2.24 (SWCLK)
SWD: J2.5, U2.25 (SWDIO)
VBUS: F1.1, F2.1, J3.1, J4.A4 (VBUS), J4.A9 (VBUS), J4.B4 (VBUS), J4.B9 (VBUS), J15.1, U3.5 (VP)
~RESET: J2.3, R1.2, U2.26 (~RUN)

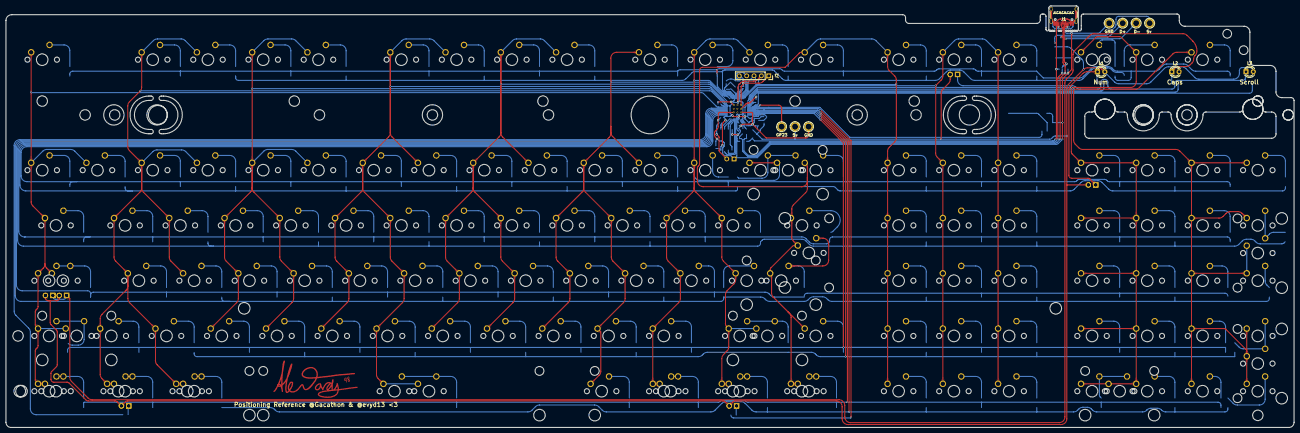
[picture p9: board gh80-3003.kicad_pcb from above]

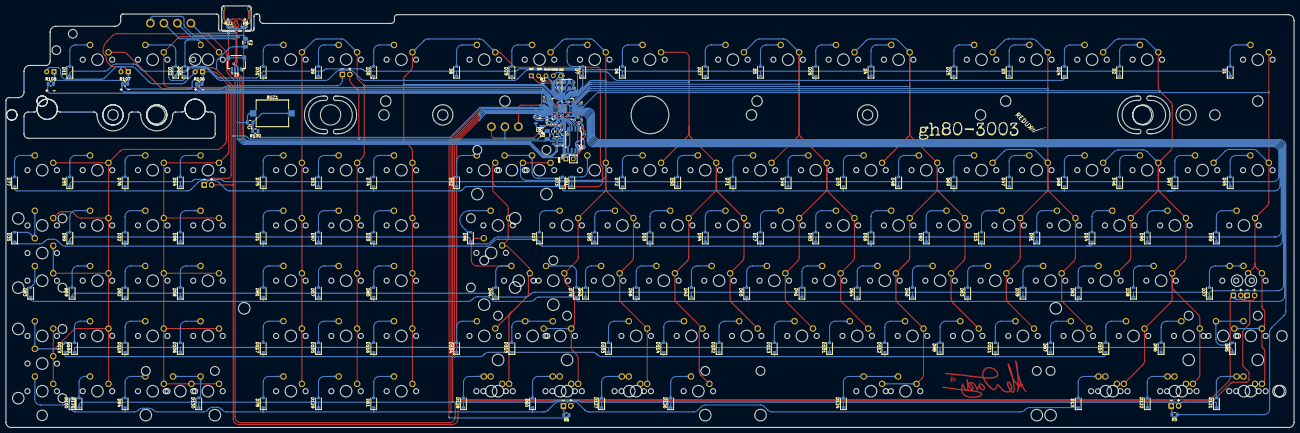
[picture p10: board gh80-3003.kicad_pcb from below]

Board: 2 copper layers, 444.1 x 145.3 mm, 316 parts (160 on the bottom side), 179 nets.

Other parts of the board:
L5#2, L5#3, L5#4: LED; CHERRY_MX_LED
